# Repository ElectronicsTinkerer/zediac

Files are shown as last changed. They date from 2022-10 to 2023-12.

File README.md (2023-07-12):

# ZEDIA Computer System

(Zach's Electronic Desktop Instrumentation and Analysis Computer)

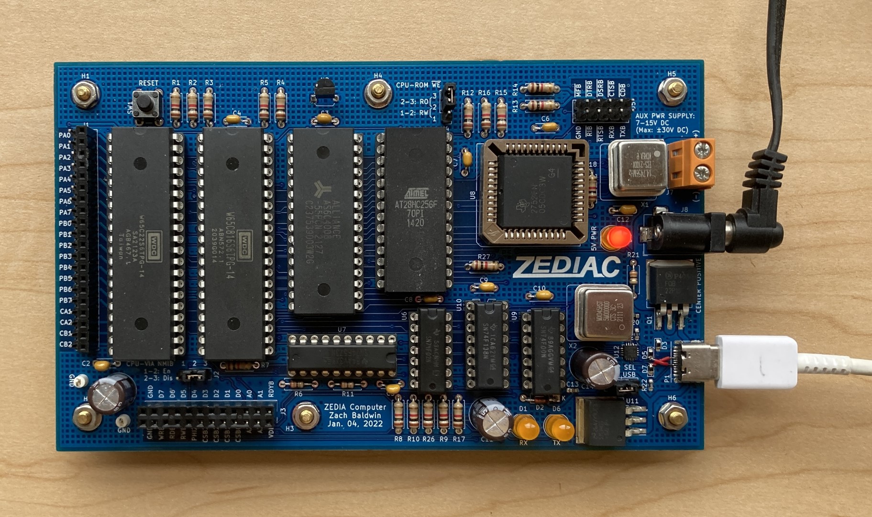
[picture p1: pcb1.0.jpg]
Top-down photo of the PCB. From left to right: GPIO connector, VIA, CPU, RAM, ROM, DUART. Below the CPU RAM and ROM are several 74xx series ICs for address decoding. The right edge of the PCB features the power and USB connectors. Note the incorrect date on the PCB-when I changed the date over from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


## System stats

* W65C816 CPU
* 32k EEPROM (with write capability)
* 512K RAM
* 65C22 VIA, providing ~20 GPIOs (really 16 + 4 handshake lines)
* ST16C2752 Dual UART
* 5+ MHz operation
* Partial system bus expansion header with address decoding
* USB-C UART interface via a CP2102
* 2 power delivery methods (unregulated voltage in via barrel jack or terminal block. Also power over USB)
* ESD protection on all IO headers

## Software

All software is available in the `software` directory. At the moment, there is a system monitor which provides many memory manipulation utilities.

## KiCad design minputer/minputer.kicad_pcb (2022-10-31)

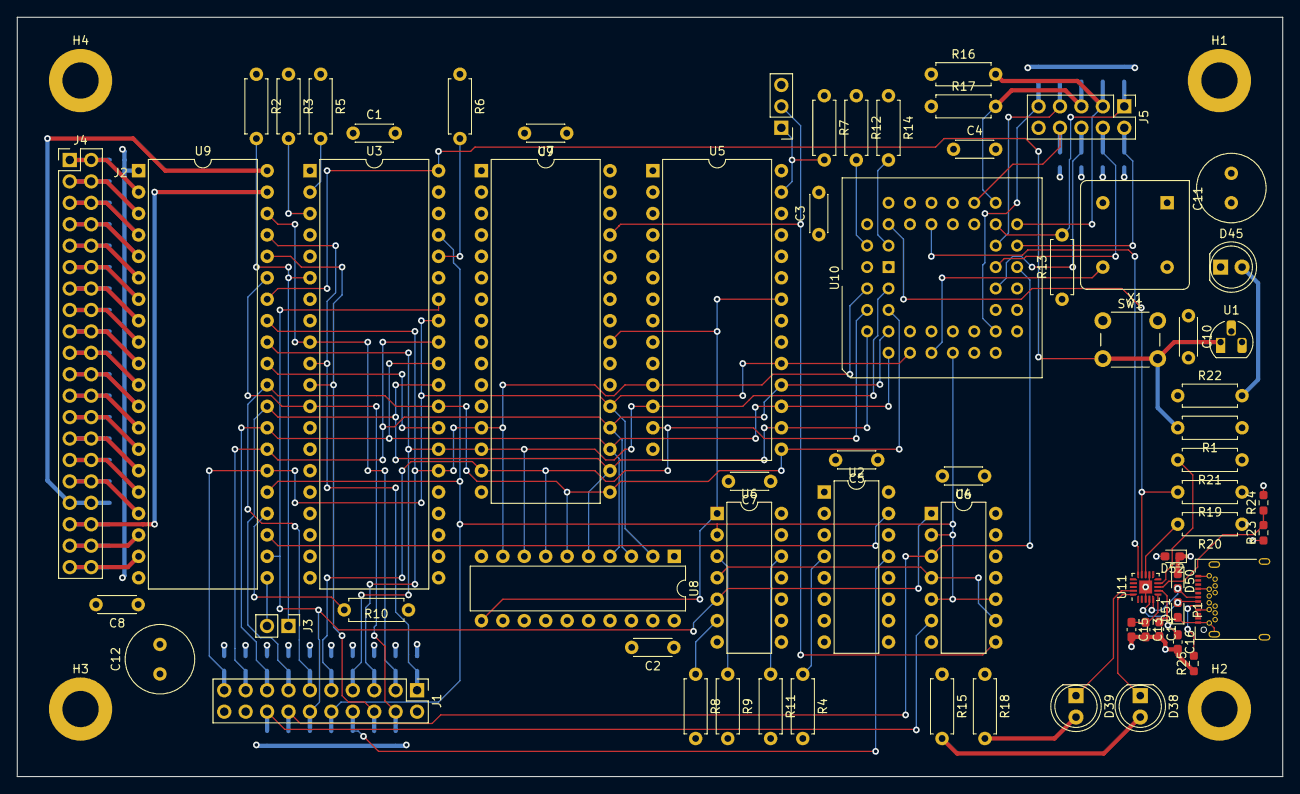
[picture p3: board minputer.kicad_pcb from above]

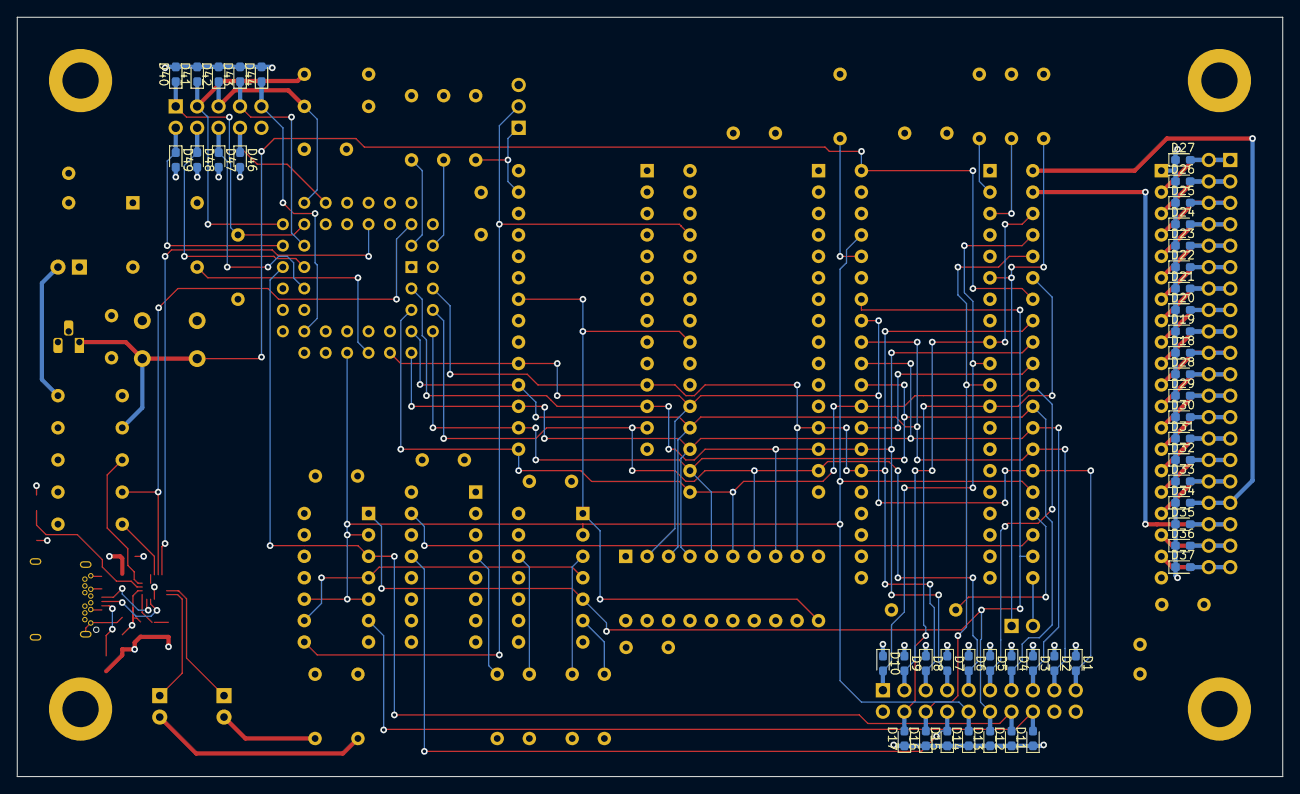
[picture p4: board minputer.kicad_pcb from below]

Board: 4 copper layers, 150.0 x 90.0 mm, 116 parts (46 on the bottom side), 107 nets.

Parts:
C1, C2, C3, C4, C5, C6, C7, C8, C9, C10: 0.1u; C_Disc_D4.3mm_W1.9mm_P5.00mm
C11, C12: 150u; C_Radial_D8.0mm_H7.0mm_P3.50mm
C13, C14: 4.7u; C_0603_1608Metric_Pad1.08x0.95mm_HandSolder
C15, C16: 0.1u; C_0603_1608Metric_Pad1.08x0.95mm_HandSolder
D1, D2, D3, D4, D5, D6, D7, D8, D9, D10, D11, D12, D13, D14, D15, D16, D17, D18, D19, D20, D21, D22, D23, D24, D25, D26, D27, D28, D29, D30, D31, D32, D33, D34, D35, D36, D37, D40, D41, D42, D43, D44, D46, D47, D48, D49, D50, D51, D52: D_TVS; D_0603_1608Metric_Pad1.05x0.95mm_HandSolder
D38, D39, D45: LED; LED_D5.0mm
H1, H2, H3, H4: MountingHole_Pad; MountingHole_4.3mm_M4_DIN965_Pad
J1: Conn_02x10_Odd_Even; PinHeader_2x10_P2.54mm_Vertical
J2: Conn_01x03_Male; PinHeader_1x03_P2.54mm_Vertical
J3: Conn_01x02_Male; PinHeader_1x02_P2.54mm_Vertical
J4: Conn_02x20_Odd_Even; PinHeader_2x20_P2.54mm_Vertical
J5: Conn_02x05_Odd_Even; PinHeader_2x05_P2.54mm_Vertical
P1: USB_C_Plug_USB2.0; USB_C_Receptacle_Amphenol_12401548E4-2A
R1, R2, R3, R4, R5, R6, R7, R8, R9, R10, R11, R12, R13, R14, R16, R17, R20, R21: 1k; R_Axial_DIN0207_L6.3mm_D2.5mm_P7.62mm_Horizontal
R15, R18, R22: 330; R_Axial_DIN0207_L6.3mm_D2.5mm_P7.62mm_Horizontal
R19: 10k; R_Axial_DIN0207_L6.3mm_D2.5mm_P7.62mm_Horizontal
R23: 22.1k; R_0603_1608Metric_Pad0.98x0.95mm_HandSolder
R24: 47.5k; R_0603_1608Metric_Pad0.98x0.95mm_HandSolder
R25: 5.1k; R_0603_1608Metric_Pad0.98x0.95mm_HandSolder
SW1: SW_Push; SW_PUSH_6mm
U1: DS1318; TO-92L_HandSolder
U2: 74LS138; DIP-16_W7.62mm
U3: W65C816; DIP-40_W15.24mm
U4: 74HC00; DIP-14_W7.62mm
U5: 28C256; DIP-28_W15.24mm
U6: 74HC02; DIP-14_W7.62mm
U7: AS6C4008-55PCN; DIP-32_W15.24mm
U8: 74LS573; DIP-20_W7.62mm
U9: W65C22; DIP-40_W15.24mm
U10: 16C2552_PLCC; PLCC-44_THT-Socket
U11: CP2102N-Axx-xQFN20; VQFN-20-1EP_3x3mm_P0.45mm_EP1.55x1.55mm
X1: CXO_DIP8; Oscillator_DIP-8

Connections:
/3V3: C13.1, C15.1, U11.6 (VDD)
/A0: D9.2 (A2), J1.3, U3.9 (A0), U5.10 (A0), U7.3 (A14), U9.38 (RS0), U10.10 (A0)
/A1: D10.2 (A2), J1.1, U3.10 (A1), U5.9 (A1), U7.28 (A13), U9.37 (RS1), U10.14 (A1)
/A2: D16.2 (A2), J1.6, U3.11 (A2), U5.8 (A2), U7.4 (A12), U9.36 (RS2), U10.15 (A2)
/A3: D17.2 (A2), J1.4, U3.12 (A3), U5.7 (A3), U7.25 (A11), U9.35 (RS3), U10.16 (CHSEL(A3))
/A4: U3.13 (A4), U5.6 (A4), U7.23 (A10)
/A5: U3.14 (A5), U5.5 (A5), U7.26 (A9)
/A6: U3.15 (A6), U5.4 (A6), U7.27 (A8)
/A7: U3.16 (A7), U5.3 (A7), U7.5 (A7)
/A8: U3.17 (A8), U5.25 (A8), U7.6 (A6)
/A9: U3.18 (A9), U5.24 (A9), U7.7 (A5)
/A10: U3.19 (A10), U5.21 (A10), U7.8 (A4)
/A11: U2.1 (A0), U3.20 (A11), U5.23 (A11), U7.9 (A3)
/A12: U2.2 (A1), U3.22 (A12), U5.2 (A12), U7.10 (A2)
/A13: U2.3 (A2), U3.23 (A13), U5.26 (A13), U7.11 (A1)
/A14: U2.5 (E2), U3.24 (A14), U4.12, U7.12 (A0)
/A15: U2.6 (E3), U3.25 (A15), U4.13, U7.22 (CE#)
/AUXCSB: D15.2 (A2), J1.8, U2.13 (O2)
/B0: U7.1 (A18), U8.12 (Q7)
/B1: U7.30 (A17), U8.13 (Q6)
/B2: U7.2 (A16), U8.14 (Q5)
/B3: U7.31 (A15), U8.15 (Q4)
/B7: U5.1 (A14), U8.19 (Q0)
/D0: D8.2 (A2), J1.5, U3.26 (D7), U5.11 (D0), U7.13 (DQ0), U8.9 (D7), U9.33 (D0), U10.2 (D0)
/D1: D7.2 (A2), J1.7, U3.27 (D6), U5.12 (D1), U7.14 (DQ1), U8.8 (D6), U9.32 (D1), U10.3 (D1)
/D2: D6.2 (A2), J1.9, U3.28 (D5), U5.13 (D2), U7.15 (DQ2), U8.7 (D5), U9.31 (D2), U10.4 (D2)
/D3: D5.2 (A2), J1.11, U3.29 (D4), U5.15 (D3), U7.17 (DQ3), U8.6 (D4), U9.30 (D3), U10.5 (D3)
/D4: D4.2 (A2), J1.13, U3.30 (D3), U5.16 (D4), U7.18 (DQ4), U8.5 (D3), U9.29 (D4), U10.6 (D4)
/D5: D3.2 (A2), J1.15, U3.31 (D2), U5.17 (D5), U7.19 (DQ5), U8.4 (D2), U9.28 (D5), U10.7 (D5)
/D6: D2.2 (A2), J1.17, U3.32 (D1), U5.18 (D6), U7.20 (DQ6), U8.3 (D1), U9.27 (D6), U10.8 (D6)
/D7: D1.2 (A2), J1.19, U3.33 (D0), U5.19 (D7), U7.21 (DQ7), U8.2 (D0), U9.26 (D7), U10.9 (D7)
/IO.CA1: D34.2 (A2), J4.33, J4.34, U9.40 (CA1)
/IO.CA2: D35.2 (A2), J4.35, J4.36, U9.39 (CA2)
/IO.CB1: D36.2 (A2), J4.37, J4.38, U9.18 (CB1)
/IO.CB2: D37.2 (A2), J4.39, J4.40, U9.19 (CB2)
/IO.PA0: D27.2 (A2), J4.1, J4.2, U9.2 (PA0)
/IO.PA1: D26.2 (A2), J4.3, J4.4, U9.3 (PA1)
/IO.PA2: D25.2 (A2), J4.5, J4.6, U9.4 (PA2)
/IO.PA3: D24.2 (A2), J4.7, J4.8, U9.5 (PA3)
/IO.PA4: D23.2 (A2), J4.9, J4.10, U9.6 (PA4)
/IO.PA5: D22.2 (A2), J4.11, J4.12, U9.7 (PA5)
/IO.PA6: D21.2 (A2), J4.13, J4.14, U9.8 (PA6)
/IO.PA7: D20.2 (A2), J4.15, J4.16, U9.9 (PA7)
/IO.PB0: D19.2 (A2), J4.17, J4.18, U9.10 (PB0)
/IO.PB1: D18.2 (A2), J4.19, J4.20, U9.11 (PB1)
/IO.PB2: D28.2 (A2), J4.21, J4.22, U9.12 (PB2)
/IO.PB3: D29.2 (A2), J4.23, J4.24, U9.13 (PB3)
/IO.PB4: D30.2 (A2), J4.25, J4.26, U9.14 (PB4)
/IO.PB5: D31.2 (A2), J4.27, J4.28, U9.15 (PB5)
/IO.PB6: D32.2 (A2), J4.29, J4.30, U9.16 (PB6)
/IO.PB7: D33.2 (A2), J4.31, J4.32, U9.17 (PB7)
/IRQB: U3.4 (IRQB), U6.10
/NMIB: J3.1, R2.2, U3.6 (NMIB)
/PHI1: U5.22 (~OE), U6.1, U7.24 (OE#), U8.11 (Load)
/PHI2: D14.2 (A2), J1.10, U3.37 (PHI2), U4.2, U4.5, U4.10, U6.2, U9.25 (PHI2), U10.13 (XTAL2)
/RBW: U4.4, U4.9, U6.4
/RDB: D12.2 (A2), J1.14, U4.3, U10.24 (~IOR)
/RES: U6.13, U10.21 (RESET)
/RESB: R1.2, SW1.2, U1.1 (RST), U3.40 (RESB), U6.11, U9.34 (RESB)
/RWB: D13.2 (A2), J1.12, U3.34 (RWB), U4.1, U6.5, U9.22 (RWB)
/UARTCSB: U2.14 (O1), U10.18 (~CS)
/VIACSB: U2.15 (O0), U9.23 (CS2B)
/WRB: D11.2 (A2), J1.16, U4.6, U10.20 (~IOW)
/~ROM_CS: U4.11, U5.20 (~CS)
/~WE: J2.2, U4.8, U7.29 (WE#)
GND: C1.2, C2.2, C3.2, C4.2, C5.2, C6.2, C7.2, C8.2, C9.2, C10.2, C11.2, C12.2, C13.2, C14.2, C15.2, C16.2, D1.1 (A1), D2.1 (A1), D3.1 (A1), D4.1 (A1), D5.1 (A1), D6.1 (A1), D7.1 (A1), D8.1 (A1), D9.1 (A1), D10.1 (A1), D11.1 (A1), D12.1 (A1), D13.1 (A1), D14.1 (A1), D15.1 (A1), D16.1 (A1), D17.1 (A1), D18.1 (A1), D19.1 (A1), D20.1 (A1), D21.1 (A1), D22.1 (A1), D23.1 (A1), D24.1 (A1), D25.1 (A1), D26.1 (A1), D27.1 (A1), D28.1 (A1), D29.1 (A1), D30.1 (A1), D31.1 (A1), D32.1 (A1), D33.1 (A1), D34.1 (A1), D35.1 (A1), D36.1 (A1), D37.1 (A1), D40.2 (A2), D41.2 (A2), D42.2 (A2), D43.2 (A2), D44.2 (A2), D45.1 (K), D46.2 (A2), D47.2 (A2), D48.2 (A2), D49.2 (A2), D50.1 (A1), D51.1 (A1), D52.1 (A1), H1.1, H2.1, H3.1, H4.1, J1.18, J1.20, J5.10, P1.A1 (GND), P1.A12 (GND), P1.B1 (GND), P1.B12 (GND), P1.S1 (SHIELD), R4.2, R8.2, R9.2, R11.2, R24.2, R25.1, SW1.1, U1.3 (GND), U2.8 (GND), U3.21 (VSS), U4.7 (GND), U5.14 (GND), U6.7 (GND), U7.16 (VSS), U8.1 (OE), U8.10 (GND), U9.1 (VSS), U10.12 (GND), U10.22 (GND), U11.3 (GND), U11.12 (GND), U11.21 (GND), X1.4 (GND)
unnamed: D38.1 (K), U11.20 (~TXT/GPIO.2)
unnamed: D38.2 (A), R15.2
unnamed: D39.1 (K), U11.19 (~RXT/GPIO.3)
unnamed: D39.2 (A), R18.2
unnamed: D40.1 (A1), J5.1, R13.2, U10.30 (~CDB)
unnamed: D41.1 (A1), J5.3, R16.2, U10.28 (~CTSB)
unnamed: D42.1 (A1), J5.5, R17.2, U10.29 (~DSRB)
unnamed: D43.1 (A1), J5.7, U10.27 (~DTRB)
unnamed: D44.1 (A1), J5.9, U10.19 (~MFB)
unnamed: D45.2 (A), R22.2
unnamed: D46.1 (A1), J5.8, U10.31 (~RIB)
unnamed: D47.1 (A1), J5.6, U10.23 (~RTSB)
unnamed: D48.1 (A1), J5.4, U10.25 (RXB)
unnamed: D49.1 (A1), J5.2, U10.26 (TXB)
unnamed: D50.2 (A2), P1.A7 (D-), U11.5 (D-)
unnamed: D51.2 (A2), P1.A6 (D+), U11.4 (D+)
unnamed: J2.1, R7.2, U5.27 (~WE)
unnamed: J3.2, U9.21 (IRQB)
unnamed: P1.A5 (CC), R25.2
unnamed: R3.2, U3.3 (ABORT)
unnamed: R4.1, U2.4 (E1)
unnamed: R5.2, U3.2 (RDY)
unnamed: R6.2, U3.36 (BE)
unnamed: R8.1, U6.6
unnamed: R9.1, U6.3
unnamed: R10.2, U9.24 (CS1)
unnamed: R11.1, U6.12
unnamed: R12.2, U10.42 (~CDA)
unnamed: R14.2, U10.43 (~RIA)
unnamed: R19.2, U10.41 (~DSRA), U11.14 (SUSPEND)
unnamed: R20.2, U11.13 (~WAKEUP)
unnamed: R21.2, U11.9 (~RST)
unnamed: R23.2, R24.1, U11.8 (VBUS)
unnamed: U10.11 (XTAL1), X1.5 (OUT)
unnamed: U6.8, U10.17 (INTB)
unnamed: U6.9, U10.34 (INTA)
unnamed: U10.36 (~RTSA), U11.15 (~CTS)
unnamed: U10.38 (TXA), U11.17 (RXD)
unnamed: U10.39 (RXA), U11.18 (TXD)
unnamed: U10.40 (~CTSA), U11.16 (~RTS)
VDD: C1.1, C2.1, C3.1, C4.1, C5.1, C6.1, C7.1, C8.1, C9.1, C10.1, C11.1, C12.1, C14.1, C16.1, D52.2 (A2), J1.2, P1.A4 (VBUS), P1.A9 (VBUS), P1.B4 (VBUS), P1.B9 (VBUS), R1.1, R2.1, R3.1, R5.1, R6.1, R7.1, R10.1, R12.1, R13.1, R14.1, R15.1, R16.1, R17.1, R18.1, R19.1, R20.1, R21.1, R22.1, R23.1, U1.2 (VCC), U2.16 (VCC), U3.8 (VDD), U4.14 (VCC), U5.28 (VCC), U6.14 (VCC), U7.32 (VCC), U8.20 (VCC), U9.20 (VDD), U10.33 (VCC), U10.44 (VCC), U11.7 (VREGIN), X1.8 (Vcc)

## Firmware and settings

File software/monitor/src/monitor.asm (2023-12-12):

;;;
;;;  ZEDIAC MONITOR
;;;
;;; (C) Zach Baldwin 2023
;;;
;;; Updates:
;;; 2023-04-01: Created file
;;; 2023-04-28: Added header includes for HW and keyboard
;;; 2023-05-16: Add VIA and UART initialization
;;; 2023-06-03: Implement basic IO and print utilities; start monitor prompt
;;; 2023-06-09: Update symbols to make use of new .def SLIME support
;;; ****-**-**: Forgot to update this header
;;; 2023-12-09: Bumped UART baud rate from 115200 to 912600 (8x)
;;; 2023-12-10: Added 'load' and 'run' commands; Switch versioning to
;;;             semantic versioning 2.0.0 -> This release: 1.8.0
;;; 2023-12-11: Completed functionality of 'load'
;;;

#include "../inc/syscalls.inc"
    
#include "../inc/hw.inc"
#include "../inc/keyboard.inc"    
;; #include "../inc/macros.inc"
    
smc_base0       .equ $7c00
smc_base1       .equ $7c80
arg_stack       .equ $7d00         
; stack_base    .equ $7e00      ; Really $7eff but for keeping things "page orientated" ...
direct_page     .equ $7f00
buf             .equ $010000    ; Input line buffer
xrecv_buf       .equ $020000    ; XMODEM receive / send buffer base
                                ; MUST BE LOCATED ON A BANK FOR THE LOAD
                                ; ROUTINE TO FUNCTION

    
GETC_LOAD       .def 50_000     ; Clock cycles
    
;;; ------------------------------------
;;;  DIRECT PAGE VARIABLES
;;; ------------------------------------
xmon_ascii_line .def 0          ; ASCII temp storage for hex monitor (17 bytes)

enum define syscall {
    tmp0 = $20,
    tmp1,
    tmp2,
    tmp3,
    tmp4,
    tmp5,
    tmp6,
    tmp7,
    tmp8,
    tmp9,
    tmp10,
    tmp11,
    tmp12,
    tmp13,
    tmp14,
    tmp15
}
    
enum define mon {
    tmp0 = $30,
    tmp1,
    tmp2,
    tmp3,
    tmp4,
    tmp5,
    tmp6,
    tmp7,
    tmp8,
    tmp9,
    tmp10,
    tmp11,
    tmp12,
    tmp13,
    tmp14,
    tmp15,
    tmp16,
    tmp17,
    tmp18,
    tmp19,
    tmp20,
    tmp21,
    tmp22,
    tmp23,
    tmp24,
    tmp25,
    tmp26,
    tmp27,
    tmp28,
    tmp29,
    tmp30,
    tmp31
}

;;; CPU frequency storage (in kHz)
cpu_freq_mhz    .equ $fc        ; 16 bits
cpu_freq_khz    .equ $fe        ; 16 bits
    

s_px_l          .def syscall.tmp0
s_px_m          .def syscall.tmp1
s_px_h          .def syscall.tmp2
    
    
xsav            .def mon.tmp0   ; 16 bits
ysav            .def mon.tmp2   ; 16 bits
arg_sp          .def mon.tmp4   ; 16 bits
line_start      .def mon.tmp6   ; 16 bits
cmd_tbl_ptr     .def mon.tmp8   ; 16 bits
wspc_skip       .def mon.tmp10  ; 8  bits
xmon_mode       .def mon.tmp11  ; 8  bits
xmon_l          .def mon.tmp12  ; 8  bits
xmon_m          .def mon.tmp13  ; 8  bits
xmon_h          .def mon.tmp14  ; 8  bits
xmon_stl        .def mon.tmp15  ; 8  bits
xmon_stm        .def mon.tmp16  ; 8  bits
xmon_sth        .def mon.tmp17  ; 8  bits
xmon_xaml       .def mon.tmp18  ; 8  bits
xmon_xamm       .def mon.tmp19  ; 8  bits
xmon_xamh       .def mon.tmp20  ; 8  bits

gs_addr_l       .def mon.tmp0
gs_addr_m       .def mon.tmp1
gs_addr_h       .def mon.tmp2
gs_argc         .def mon.tmp3
gs_mode         .def mon.tmp4
    
args_y          .def mon.tmp0
args_end        .def mon.tmp2

xr_blk          .def mon.tmp0   ; 8  bits
xr_blkptr       .def mon.tmp1   ; 24 bits!
xr_chksum       .def mon.tmp4   ; 8  bits
xr_isnext       .def mon.tmp5   ; 8  bits
xr_retry_num    .def mon.tmp6   ; 8  bits
xr_init_done    .def mon.tmp7   ; 8  bits

xs_addr_l       .def mon.tmp0   ; 8  bits
xs_addr_m       .def mon.tmp1   ; 8  bits
xs_addr_h       .def mon.tmp2   ; 8  bits
xs_count        .def mon.tmp3   ; 16 bits
xs_blk          .def mon.tmp5   ; 8  bits
xs_chksum       .def mon.tmp6   ; 8  bits

copy_s_l        .def mon.tmp0   ; 8  bits
copy_s_m        .def mon.tmp1   ; 8  bits
copy_s_h        .def mon.tmp2   ; 8  bits
copy_d_l        .def mon.tmp3   ; 8  bits
copy_d_m        .def mon.tmp4   ; 8  bits
copy_d_h        .def mon.tmp5   ; 8  bits
copy_c_l        .def mon.tmp6   ; 8  bits
copy_c_m        .def mon.tmp7   ; 8  bits
copy_c_h        .def mon.tmp8   ; 8  bits (written to but unused)
copy_xy         .def mon.tmp9   ; 16 bits
copy_mode       .def mon.tmp11  ; 8  bits

load_count_l    .def mon.tmp0   ; 8  bits
load_count_h    .def mon.tmp1   ; 8  bits
load_addr_l     .def $40        ; 8  bits (start address)
load_addr_m     .def $41        ; 8  bits
load_addr_h     .def $42        ; 8  bits

;;; ------------------------------------
;;;  ROM SIZE AND BASE
;;; ------------------------------------
    .rom ROM_SIZE
    .org ROM_BASE

;;; ------------------------------------
;;;  SYSCALL TABLE
;;; ------------------------------------
;;; SYSCALLS can be accessed by loading
;;; X with the syscall index then simulating
;;; a jsl (syscall_table,x) instruction.
;;; Alternatively, (a slightly less portable
;;; method is to) just jsl to the syscall
;;; subroutine name
syscall_table: 
    .word sys_delay
    .word sys_puthex
    .word sys_putdec
    .word sys_puthex_word
    .word sys_putdec_word
    .word sys_putc
    .word sys_puts
    .word sys_getc
    .word sys_getc_nb
    .word sys_getc_to
    .word sys_parsehex
    .word sys_memcpy_init
    .word sys_memcpy
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

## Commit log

2022-10-30 Realize project is not in git; Complete most of schematic
    [minputer.kicad_pcb, minputer.kicad_sch]
2022-10-31 Finish schematic
    [minputer.kicad_sch]
2022-10-31 Assign footprints
    [minputer.kicad_pcb, minputer.kicad_sch]
2022-10-31 Component placement and TVS routing finished
    [minputer.kicad_pcb, minputer.kicad_sch]
2022-10-31 Remove extra 7400
    [minputer.kicad_pcb, minputer.kicad_sch]
2022-10-31 Track size change 0.2->0.1524
    [minputer.kicad_pcb]
2022-10-31 Route BUS connector
    [minputer.kicad_pcb]
2022-11-14 Complete initial routing
    [minputer.kicad_sch]
2022-11-17 Clean up silk screen
    [minputer.kicad_sch]
2022-12-27 Add aux power input; reroute CP2102; add PHI2 osc
    [minputer.kicad_sch]
2022-12-27 Add GND TPs; generate logo symbol/model files
    [minputer.kicad_sch]
2022-12-27 Rename project minputer->zediac
    [zediac.kicad_sch]
2022-12-27 Add silk labels for connectors and jumpers
    [zediac.kicad_sch]
2023-01-04 Silk cleanup; add UART INT pulldown resistors
    [zediac.kicad_sch]
2023-01-04 Fix reversed databus on '816
    [zediac.kicad_sch]
2023-01-04 Correct CP2102 power supply
    [zediac.kicad_sch]
2023-01-04 Change USB footprint
    [zediac.kicad_sch]
2023-01-05 Change DS1813 footprint
    [zediac.kicad_sch]
2023-01-05 Export BOM
2023-01-06 Generate gerbers
2023-06-04 Finish UART init, implement syscalls for printing
2023-06-04 Fix backspace; fix _sys_puts pointer offset
    [monitor.asm]
2023-06-04 Correct dbr value; correct backspace; clear screen on reset
    [monitor.asm]
2023-06-11 Fix 'info' command; fix cli args tokenization and stack set up
    [monitor.asm]
2023-06-11 [mon] Correct backspace graphical behavior
    [monitor.asm]
2023-06-20 [mon] Implement go/gosub and SYS_PARX Also: * Improve MONITOR docs (big comment) * Correct SYS_GETCNB p.c return behavior
    [monitor.asm]
2023-06-23 [pcb] Correct PCB design date in SILK
2023-06-26 [mon] Fix ASCII not printing on some hex dump lines
    [monitor.asm]
2023-06-27 [mon] Print index across top of hex dump
2023-06-27 [mon] Correct GO/GOSUB command jump indirect (pointer) address
    [monitor.asm]
2023-06-29 [mon] XRECV now works (in 816CE)! Key points: * Forgot the ACK after a successful block transfer * Added a flush/purge to the Rx UART FIFO prior to sending NAK * General logic corrections
    [monitor.asm]
2023-07-02 [pcb] Correct EEPROM /OE signal; Remove reduandant gate; Bump Rev1.0->1.1
    [zediac.kicad_sch]
2023-07-07 [mon] Correct argv stack bug introduced in 4253b3d8
    [monitor.asm]
2023-07-07 [mon] Print the parsed command name which is not found
2023-07-08 [mon] Fix crash on XRECV (jsr -> jsl) Also: * Correct cold reset delay arg passing * Fix getc_to delay check ordering (bug introduced in 426e6bf7) This resulted in delays of X-1 instead of X seconds
    [monitor.asm]
2023-07-08 [mon] Fix sys_printdec with single digit numbers
    [monitor.asm]
2023-07-08 [mon] Correct 'memmap: command not found'
    [monitor.asm]
2023-07-08 [mon] Correct COPY using incorrect bank for SMC
    [monitor.asm]
2023-07-08 [mon] Further correct XRECV timing; fix memcpy cound offset
    [monitor.asm]
2023-07-10 [mon] Fix startup getc timeout by initializing cpu_freq_mhz with dummy value
    [monitor.asm]
2023-07-13 [mon] Move syscall table to start of ROM; Print return value from GOSUB
2023-12-09 [lib-curses] Don't print leading 0's in movexy
2023-12-09 [mon] Bump UART baud rate (115200 -> 912600)
2023-12-09 [mon] Correct puthex_word documentation
    [monitor.asm]
2023-12-24 [pcb] Update to KiCad 7
    [zediac.kicad_sch]
2023-12-24 [pcb] Add reset jumper/header
    [zediac.kicad_sch]
2023-12-24 [pcb] Add TVS to reset line
    [zediac.kicad_sch]
